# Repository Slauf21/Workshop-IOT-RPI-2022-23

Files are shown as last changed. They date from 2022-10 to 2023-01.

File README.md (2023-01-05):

# Workshop-IOT-RPI-2022-23

Steeds meer dingen – auto’s, deurbellen, rookmelders, koelkasten, noem maar op – zijn via een ‘embedded systeem’ verbonden met het internet. Internet of Things (IoT) noemen we dat. Hoe werken die systemen en wat zijn de elementaire bouwstenen om een volwaardig IoT-device te maken? In deze workshop bouwen we een eerste IoT-device. We bouwen een koppeling tussen sociale media (Telegram) en een “thing” met behulp van een Raspberry Pi-computertje verbonden met een temperatuur en luchtvochtigheid sensor, een bewegingssensor, een camera, een lichtsensor en een versnellingssensor. Dit alles doen we op een laagdrempelige manier. Alles is beschikbaar zodat je thuis - met je eigen Raspberry Pi – het werk kan voortzetten, als je dat wil.

Onderstaande linken om de benodigde applicaties te downloaden: <ins>*Indien je van thuis volgt.*</ins>

- Editor: [Notepad++](https://notepad-plus-plus.org/downloads/) (installeer de laatste versie)
- FTP-client: [FileZilla](https://filezilla-project.org/download.php?type=client)
- SSH-client: [Putty](https://www.chiark.greenend.org.uk/~sgtatham/putty/latest.html) (MSI Windows Installer: 64-bit x86:)

**Indien je de workshop volgt mag je beginnen bij [Stap 2](#2-aanmaken-van-telegram-bot).**

# Inhoudstabel

- [Workshop-IOT-RPI-2022-23](#workshop-iot-rpi-2022-23)
- [Inhoudstabel](#inhoudstabel)
- [1. Installeren en Configureren Raspberry Pi](#1-installeren-en-configureren-raspberry-pi)
  - [1.1. Installeren Raspberry Pi OS](#11-installeren-raspberry-pi-os)
  - [1.2. Raspberry Pi verbinden met wifi](#12-raspberry-pi-verbinden-met-wifi)
  - [1.3. Configureren Raspberry Pi](#13-configureren-raspberry-pi)
- [2. Aanmaken van Telegram Bot](#2-aanmaken-van-telegram-bot)
  - [2.1 Installeer Telegram](#21-installeer-telegram)
  - [2.2 Configureren van bot](#22-configureren-van-bot)
- [3. Schrijven van de code](#3-schrijven-van-de-code)
  - [3.1 Putty](#31-putty)
  - [3.1 FileZilla](#31-filezilla)
  - [3.1 Notepad++](#31-notepad)

# 1. Installeren en Configureren Raspberry Pi

Om de Raspberry PI te kunnen gebruiken voor het IOT-project moet eerst het Raspberry Pi operating system geïnstalleerd worden. Daarna moet de wifi op de Raspberry Pi geconfigureerd worden en het IP-adres genoteerd worden zodat vanaf een andere pc ingelogd kan worden op de PI via SSH. Als je de workshop volgt tijdens de demo kan je deel 1 volledig overslaan en naar deel 2 gaan. Wil je het project bij je thuis nabouwen, dan moet je eerst stap 1.1 doornemen om het project te kunnen opbouwen.

## 1.1. Installeren Raspberry Pi OS

Om het project te kunnen opstellen moet het Raspberry PI operating system geïnstalleerd worden (op een SD-kaart van minstens 16GB die volledig geformatteerd mag worden) samen met enkele installatie pakketten. Bij de Raspberry Pi die tijdens de workshop gebruikt wordt is dit al uitgevoerd. Om dit thuis ook te kunnen doen moet dit eerst nog op de SD-kaart geïnstalleerd worden. 

Eerst moet de [Raspberry Pi Imager](https://www.raspberrypi.com/software/) geïnstalleerd worden op je computer. De imager is een snelle en makkelijke manier om de Raspberry Pi OS te installeren op een SD kaart.

Steek de SD kaart in je computer en open de imager. Bij het openen van de imager word je begroet met het volgende scherm:



Om de OS te installeren klik je op 'CHOOSE OS' en selecteer je Raspberry Pi OS (32-bit). Daarna kies je de SD kaart waarop je de OS wilt zetten. Dit gebeurt door op de 'CHOOSE STORAGE' knop te klikken. Je SD kaart zal daar staan en die moet je dan selecteren.

Wanneer je de melding krijgt dat het schrijven van de image succesvol afgerond is mag je de kaart verwijderen uit je pc en in de Raspberry Pi plaatsen. Sluit vervolgens het toetsenbord, muis, camera, HDMI-scherm, en sensor bord aan. De sensoren bord is al gemaakt tijdens de workshop. Als je deze zelf wil maken kan je [hier](https://github.com/Slauf21/Workshop-IOT-RPI-2022-23/blob/main/Circuit/PCB.md) meer informatie vinden.

Nu is de Raspberry Pi klaargezet maar deze moet nog geconfigureerd worden.

## 1.2. Raspberry Pi verbinden met wifi

- Steek de Raspberry Pi in en wacht tot deze is ingeschakeld.

Startscherm:

(https://postimg.cc/5X9Gnrcb)

- Klik rechtsboven op het wifi-icoontje. Schakel de wifi in en kies voor je wifi netwerk.

(https://postimg.cc/HrsMnwM6)

- Na het selecteren van het netwerk komt er in het midden een venster tevoorschijn. Vul hier het wachtwoord van je netwerk in.

(https://postimg.cc/7GSH4Lxg)

Nu de Raspberry Pi verbonden is met het netwerk bewaren we het toegewezen IP-adres. Door over het wifi-icoontje te bewegen met de cursor zal er een venster verschijnen. Noteer deze IP-adres. Wees zeker dat je raspberry pi en je PC verbonden zijn met hetzelfde wifi netwerk.

(https://postimg.cc/k24kcH8K)

*Ons IP-adres: 169.154.146.220, niet overnemen.*

## 1.3. Configureren Raspberry Pi

Op de raspberry pi moeten we nu SSH aanzetten. Dit wordt gedaan door linksboven op de raspberry pi symbool te klikken en dan **Preferences** en dan **Raspberry Pi Configuration**. Onder de interfaces tab click je dan ssh aan.



Als volgende stap gaan we met een voorgeschreven .sh file de nodige bibliotheken afhalen en functionaliteiten aanzetten van de RPI.

Open Putty op je PC. Je wordt begroet met het volgende scherm:



Hier moet je bij hostname het ip adres van de raspberry pi ingeven. Het is noodzakelijk dat de PC en de raspberry pi op hetzelfde wifi netwerk zitten. Dan voer je als poortnummer 22 in en kies je SSH als connectie type. Dan druk je op **Open**.

- *Mogelijke waarschuwing: klik op 'Accept'*

(https://postimg.cc/R3xjwL1z)

Vervolgens zal je moeten inloggen op de Raspberry Pi. Gebruik de standaard inloggegevens als volgt:

- login as: **pi** (enter)
- password: **raspberry** (enter)

Als je je eigen login gegevens hebt gekozen, vul je die in.

*Telkens wanneer je opnieuw wilt inloggen met Putty moet je deze stappen herhalen.*

Indien je succesvol bent ingelogd ziet je terminal als volgt uit:

(https://postimg.cc/HVDD8PBP)

*Inloggegevens ter illustratie, niet overnemen.*

Met onderstaande commando's gaan we als eerst de .sh downloaden en vervolgens uitvoeren. Kopieer ze uit deze handleiding en plak ze in de putty terminal. Het plakken in een terminal wordt gedaan met de rechtermuisknop, i.p.v. de sneltoets ctrl+V. Druk op enter om ze uit te voeren.

- Downloaden script:
```javascript
wget https://raw.githubusercontent.com/Slauf21/Workshop-IOT-RPI-2022-23/main/Files/install.sh
```
- Script uitvoerbaar maken:
  - chmod +x install.sh
- Starten van script:
  - sudo ./install.sh

*Kopieer deze commando's individueel en plak met rechtermuisknop in de terminal.*

Vervolgens zal de RPI herstarten en kan er verder gegaan worden met de volgende stap.

*Log opnieuw in via Putty.*

Om nu de camera te activeren voor gebruik voer je volgende commando's in Putty.

- sudo raspi-config

(https://postimg.cc/LnmbSVKR)

- Schuif naar onder met pijltjes op het toetsenbord tot 'Interface Options' en klik op enter

(https://postimg.cc/QFFGLq1C)

- Klik op enter waar 'Legacy Camera' vermeld staat

(https://postimg.cc/CBLstcn6)

- Klik nu weer op enter om de camera te activeren

(https://postimg.cc/hhmXn98C)

- Klik een laatste keer op enter om de waarschuwing te sluiten

(https://postimg.cc/944WphJx)

Om het configuratiescherm af te sluiten toets je 'Esc' (linksboven op het toetsenbord) in.

# 2. Aanmaken van Telegram Bot

## 2.1 Installeer Telegram
We beginnen met het installeren van Telegram. Deze kan zowel op pc als op mobiel geïnstalleerd worden. Volg deze link om [Telegram Desktop](https://desktop.telegram.org/) te installeren op pc.

## 2.2 Configureren van bot
- Open telegram en zoek naar BotFather.

(https://postimg.cc/XGbcST7m)

Onderstaande venster bij invoer BotFather:

*Elk <ins>commando</ins> begint met een slash (/).*

(https://postimg.cc/ZCDGbRS3)

- Klik vervolgens op start.

Hierna verschijnt een hoop uitleg van verschillende commando's voor het aansturen van de bot.

- Om nu een bot te creëren voeren we '/newbot' in.

(https://postimg.cc/t7tpFfZT)

- Kies een naam voor je bot.

(https://postimg.cc/0r2KMpjL)

- Kies nu een gebruikersnaam voor je bot dat eindigt met bot (bv. test_bot). 

(https://postimg.cc/jDN4gzzM)

*Gebruik iets anders als 'Telegram_bot'.*

Indien naam in gebruik kan er nogmaals gevraagd worden om een gebruikersnaam in te voeren.

- Als dit succesvol is gelukt, wordt er een unieke token aangemaakt die later gebruikt wordt in de software.

(https://postimg.cc/QVJc247K)

Nu de **token** is gegenereerd gaan we niet meet met de BotFather praten, maar met onze eigen bot.

- In de zoekbalk moet je zoeken naar de gebruikersnaam van je bot (bij ons geval is dat "slauf_bot"). Die voeg je dan toe en druk je op start.



We gaan ook de chat id nodig hebben. Met deze [link](https://ungineer.github.io/chatid.html) kan je de chat id terugvinden door je **token** in het venster te plakken.

- Plak de **token** in het vakje en klik op 'Get Chat ID'.

(https://postimg.cc/5YFwP56V)

# 3. Schrijven van de code

Nu de Raspberry Pi is geïnstalleerd kunnen we beginnen met het schrijven van een Python code. Om de code te schrijven hebben we als eerst een editor nodig. Om de code te transporteren op de Raspberry Pi hebben we vervolgens een FTP-client nodig. En als laatste een SSH-client om commando's uit te voeren op de Raspberry Pi. Deze had je in het begin moeten installeren.

## 3.1 Putty

- Open Putty en voer de IP-adres in die je had teruggevonden in de vorige stappen.
- *Kijk na of 'Connection type' op SSH staat en 22 als poortnummer is gekozen.*
- Klik onderaan op 'Open'.

Er wordt nu een verbinding gemaakt met het bovenvermelde adres.

Putty

Vervolgens zal je moeten inloggen op de Raspberry Pi. Gebruik de standaard inloggegevens als volgt:

- login as: **pi** (enter)
- password: **raspberry** (enter)

<br>

Indien je succesvol bent ingelogd ziet je terminal als volgt uit:

(https://postimg.cc/HVDD8PBP)

*Inloggegevens ter illustratie, niet overnemen.*

Hierna kunnen we aan de slag met het downloaden van de start code. Deze wordt bewaard op de Raspberry Pi met de volgende commando:

```javascript
wget https://raw.githubusercontent.com/Slauf21/Workshop-IOT-RPI-2022-23/main/Python_bot/Workshop.py -O ~/Desktop/Workshop.py
```

*Bestand bewaard op bureaublad.*

## 3.1 FileZilla

- Open FileZilla en voer de gegevens in die je had teruggevonden in de vorige stappen.
  - Host: IP-adres
  - Gebruikersnaam: **pi**
  - Wachtwoord: **raspberry**
  - Poort: 22
- Klik op 'Snelverbinden' om een verbinding te maken.

(https://postimg.cc/qzB1PnLQ)

Indien je succesvol bent ingelogd ziet je scherm als volgt uit:

(https://postimg.cc/8sytRcRY)

*Links zie je de werkomgeving van je pc en rechts die van de Raspberry Pi. Nu kan er bestanden uitgewisseld worden tussen deze 2 apparaten.*

- Ga nu in de map 'Desktop' die je rechts terugvindt.
- Binnen Desktop vind je nu 'Workshop.py' die eerder was afgehaald met een link.

(https://postimg.cc/zyjTwPWk)

- Sleep deze bestand nu naar je bureaublad van je <ins>pc</ins>.

(https://postimg.cc/JHmFF26z)

## 3.1 Notepad++

- Open Notepad++ en klik linksboven op 'Bestand'.

(https://postimg.cc/CBmqkZqL)

- Klik op 'Openen' en kies voor 'Workshop.py' die op je persoonlijke bureaublad staat.

(https://postimg.cc/p5Cq9X2D)

Indien je de bestand succesvol hebt kunnen openen ziet je scherm als volgt uit:

(https://postimg.cc/HjStptyT)

- Plak vervolgens de token en chat id binnen de aanhalingstekens.

- Om deze wijziging op te slaan druk op Ctrl + S of via 'Bestand' linksboven 'Opslaan' klikken.

- Open FileZilla en sleep deze bestand vanuit je persoonlijke bureaublad aan de rechterkant binnen het map 'Desktop'.

(https://postimg.cc/yWd7gVk0)

*Vink 'Deze actie altijd gebruiken' en klik op 'OK' als je een waarschuwing krijgt over 'Doelbestand bestaat al'.*

Nu de bijgewerkte versie van de code op de Raspberry Pi staat kunnen we deze runnen.

- Open Putty en tik 'cd Desktop/' in om in het bureaublad te zitten waar de code zich bevindt.

- Tik nu 'python3 Workshop.py' in om de code te runnen.

Indien je de bestand succesvol hebt kunnen runnen ziet je scherm als volgt uit:

(https://postimg.cc/t1pNDv6G)

Nu heb je de basis bereikt, om nu de interessante delen toe te voegen in je code klik je op deze [link](https://github.com/Slauf21/Workshop-IOT-RPI-2022-23/wiki).

Verder zal je hardware aansturen gelijk PiCamera om foto's te nemen, DHT11 om temperatuurmetingen uit te voeren enzovoort.

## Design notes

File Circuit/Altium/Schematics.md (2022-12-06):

# Schematic

[RPI pins header detailed](https://user-images.githubusercontent.com/79916416/205603582-8edb5c64-c594-4c13-aa63-774d3fb8d8f8.png)

The PCB will be designed in Altium designer. In Altium create a new project and add a schematic to the project. The components will be put on this schematic. 
A lot of the sensors we read are external, meaning they are their own circuit boards and need to be connected with headers. The PCB will sit on the RPI headers. 
Here are the measurements of the pin headers:


*Measurements in millimeters*

[Library Loader](https://www.samacsys.com/altium-designer-library-instructions/) is a software that allows you to import libraries for components. These include pre made footprints and schematic icons. This will be used for the SGP40 sensor

## Pin Header
These pin headers are not basic components in Altium and need to be created with a footprint wizard. Before starting create a libs folder in the Altium project.

 <br>
*Libs Folder*

### PCB Footprint
To add a custom component right click the project (.PrjPcb file) 
then **Add New To Project** -> **PCB Library**. The new file will be openned and will be blank. On the left panel a footprint is visible. This one wont be used. Press **CTRL+S** and save the file in the **Libs** folder.

<br>
*Default Footprint*

<br>

First the header for the RPI GPIO will be created. To create a new footprint press the **Tools** tab on the toolbar and select **Footprint Wizard**. A new Footprint Wizard window will open. Press next and select the type of footprint needed. A header is a **Dual In Line Package (DIP)**. Change the unit of measurement to **millimeters**

Next you will be asked for the hole dimensions. The dimensions from the measurements above need to be used. The pin diameters of the header is 1.02mm. A slightly wider diameter of 1.2mm will be used so the header can fit into the holes easily. Dimensions of the pad can be 2mm by 2mm. 

<br>
*Hole Dimensions*

<br>

Press next and now the distance between the pins need to be determined. The measurements say thet header pins are 2.54mm from each other. Since the hole and pad size was set to 2mm by 2mm there will be 1mm from the hole center to the edge of the pad. This will result in 0.54mm of free space between the pads.

<br>
*Hole Distance*

<br>

The width of the outline can be left as it is. This outline will be deleted later.
Next the total number of pins need to be selected. The rpi 3b has 40 GPIO pins in a 2x20 structure.

<br>
*Pin Amounts*

<br>

Call it RPI-Header and then click finish.

The design will appear on screen and the first this that needs to be done is to delete the yellow outline by selecting it and pressing delete. Then delete the original footprint. Result:

<br>
*New Footprint*

### Schematic Icon

A new component also needs a schematic icon to put on the schematic design. This is done by adding a schematic library to the project like a PCB library was added. 
Name it the same as the PCB library and save it under the same directory (Libs). Select the icon item and press edit. Under the new tab call the icon **RPI-Header*. The custom footprint needs to be linked to this icon. This is done by pressing the add footprint button at the bottom.

A window will appear to select a library. Press browse, then select the correct library called RPI-Header.

<br>
*Add Footprint*

<br>
*Select Library*

Press OK, then OK again. The footprint is succesfully linked to the icon. Now an actually schematic icon needs to be created.

To do this press **Tools** -> **Symbol Wizard** in the toolbar. A new window will apear asking the layout. RPI gpio has 40 pins in a zig zag style. Seelct zig zag in the layout style. Now all the pins are set as inputs. Select them all by first selecting the first, then holding shift and pressing the last one. Change the electrical type from Inputs to I/O by clicking the drop down menu of the last item.

<br>
*Icon Design*

Then **Place** -> **Place New Symbol**

In the SCH LIB window select the icon and press place. Place it somewhere on the schematic. Double click it and give it the name J1

## Sensors

The same process needs to be repeated for the sensor headers. This is a 5x1, 3x1 and 2 times 1x4 headers. When creating a one dimensional header like a 4x1. Select 8 pins for the DIP and remove one of the sides.



## Screw Terminals

The screw terminals dont have the same measurments as pin headers. 

<br>
*Screw Terminal Header*

<br>
*Hole Measurements*

<br>
*On Schematic*

## Relais

The relais has a much different pin design the a header or terminal. 

<br>
*Relais Measurements*

<br>
*Footprint*

The distance is the distance that was written in mm in the datasheet converted to mils.

<br>
*Schematic Icon*

The schematic icon pin numbering is the same as the pins on the datasheet of the relais.

## Resistors and Capacitors

Throught hole resistors are used. These are already included in the standard library of Altium. In the components search, select miscellanious devices from the drop down menu and search for Res1. The same method is used for importing capactitors.

<br>
*Miscellanious Devices*

## Wiring the Schematic

After adding all the components, the schematic should look like this:

<br>
*Schematic Not-Wired*

Now all the components need to be wired to the RPI header. For this, a [rpi gpio pinout](https://www.raspberrypi.com/documentation/computers/images/GPIO-Pinout-Diagram-2.png) picture is usefull. The right side of the gpio pins should be used as much as possible because the pcb is going to sit on the right side of the RPI.

Pin 16 is a free GPIO pin that will be used to drive the transistor base. Connect it to the pin number 2 of transistor Q1 with the 1.2k ohm resistor in between. The collector of the transsitor needs to be connected to the 5V power supply of the RPi which is pins 2 or 4. This will then power the coil, which needs to be connected to the emitter of the transtor (pin 3). Wires can be placed using CTRL+W command. Looking at [the data sheet of the relais](https://www.mouser.be/datasheet/2/307/Omron_(ENG)G5PZ_E-1843616.pdf), the coil is between pins 1 and 4 and the contact is between 2 and 3. Connect the Emitter of the BJT to pin 1 of the relais, then connect pin 4 to ground of the RPI.

Then the screw terminals need to be connected through the contact of the relais. Pins 2 and 3 can be connected since they are neutral and earth, but pins one will be live and need to go to the contact of the coil. The fly back diode 1n4007G needs to be connected reverse and in parallel with the coil. This means the anode will be connected to pin 4 and the kathode to pin 1 of the relais. 

The [DHT11](https://www.google.com/search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) has 3 connected pins. Vcc, Data and fround. It also needs a resistor between the data and the 5V. Pin 1 will be connected to the same 5V pin. Pin 2 will be connected to pin7 which is the gpio pin that support 1 wire protocol. 3 is not connected and 4 is ground which is pin 6. Also connect the 10k resistor between dht pins 1 and 2.

The mic uses and SPI ADC to convert the analog data to digital. Here are its pinouts:

<br>
*LTC1864 Pinouts*

Align the headers in the schematic to match the pinouts. This will create less confusion.

<br>
*Schematic Pinout LTC1864*

This component is devided into tho headers, one 4x1 header for each side. Vcc (Pin8) and Vref (pin1) need to be connected with 5V. [Here](https://www.cuidevices.com/product/resource/cma-4544pf-w.pdf) is the mic basic operation circuit. The output will go to the SPI adc converter.

Pins 5 (CONV),6 (SDO) and 7 (SCK) are the SPI pins. The SDO and SCK need to be connected to the MISO and SCLK pins on the RPI respectivly. WHich are pins 21 and 23. The CONV pin is the slave select and needs to be connected to SPI0 CE1 pin.

The [PIR motion sensor](https://www.mouser.be/datasheet/2/737/pir_passive_infrared_proximity_motion_sensor-932858.pdf) has 3 simple connectors. Pin 1 is the vcc, Pin2 is the data and pin 3 is the GND. Pin 22 will be used for the data of the PIR motion sensor.

The [gas sensor](https://www.mouser.be/datasheet/2/682/Sensirion_Gas_Sensors_Datasheet_SGP40-2001008.pdf) also has a reading circuit. This will be recreated in altium.

## Result

The schematic will look like this:

<br>
*Resulting Schematic*

Then the next step is to design the PCB. This can be read [here](https://github.com/Slauf21/Workshop-IOT-RPI-2022-23/blob/main/Circuit/Altium/PCB.md).

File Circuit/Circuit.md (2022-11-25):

# Circuit
TO BE UPDATED

## RPI componenten
| Component | Beschrijving | Aantal |
|---|---|---|
| RPI 3b | Raspberry Pi 3b | 1 |
| 16GB SD | SD kaart 16GB | 1 |
| RPI camera | Raspberry Pi Camera | 1 |
| Micro USB adapter | Micro USB Adapter | 1 |

## Circuit componenten
| Component | Beschrijving | Hoeveelheid |
|---|---|---|
| DHT-11 | Temperatuur-Luchtvochtigheid sensor | 1 - |
| G5PZ-1A-E 5VDC | Relais - Spoel 5V | 1 - |
| DYP-ME003 | Beweging sensor | 1 |
| 1x3 | Schroef terminal | 2 - |
| 2x20 | RPI Header | 1 - |
| 1n4007g | Flyback Diode | 1 - |
| 10kohm | Weerstand | 1 - |
| 1.2kohm | Weerstand | 1 - |
| SGP30 | Gas Sensor | 1 - |
| MAX 4466 | Microfoon | 1 - |
| TCS34725 | RGB sensor | 1 |
| SSOP8 | SPI-ADC | 1 - |
| 2n2222 | BJT transistor | 1 - |

## Schematic 

Read about how the pins of the circuit are connected and how it is designed [here](https://github.com/Slauf21/Workshop-IOT-RPI-2022-23/blob/main/Circuit/Altium/Schematics.md).

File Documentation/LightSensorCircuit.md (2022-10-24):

# Light Sensor Circuit
The LDR needs to be read with an ADC then sent to the RPI.

## LDR
LDR: https://www.gotron.be/ldr-photoresistor-100mw-50-160kohm.html

The LDR will assume a resistance value depending on the incidence of light. The voltage across this will therefore vary and be an analog value. For this we need an ADC.



## ADC
ADC TLC549: https://www.gotron.be/8-bit-adc-converter-with-serial-control.html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

Datasheet: https://pdf1.alldatasheet.com/datasheet-pdf/view/28912/TI/TLC549.html



### Working Principle

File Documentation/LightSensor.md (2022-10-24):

# Light Sensor
LDR inlezen via een adc en doorsturen naar de raspberry pi met SPI.

## LDR
LDR: https://www.gotron.be/ldr-photoresistor-100mw-50-160kohm.html

De LDR gaat een weerstandswaarde aannemen afhankelijk van de lichtinval. De spanning hierover gaat dus varieren en een analoge waarde zijn. Hiervoor hebben we een ADC nodig.



## ADC
ADC TLC549: https://www.gotron.be/8-bit-adc-converter-with-serial-control.html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



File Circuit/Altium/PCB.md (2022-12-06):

# PCB 

Add a PCB document to the project like you added a schematic. The first step will be to define the boards shape. It will go over the RPI and allign with the screwholes on the RPI. These measurements of the rpi can be found its [datasheet](https://static.raspberrypi.org/files/product-briefs/Raspberry-Pi-Model-Bplus-Product-Brief.pdf).

The PCB will come on the RPI like this:



Define the PCB Shape by first adding the holes. These are regular holes with diameter that alligns to the screwholes. The distances need to be placed correct too like in the measurements. The command jump to location can be used for precise movements. This is done by clicking J on the keyboard and then new location. 

For the shape itself switch to the mechanical layer and then use the same jump to location position to trace wires across the board:

<br>
*Wires Board Shape*

Round edges will make the PCB cleaner. The RPI has 3.0mm radius on its edges. This will be copied on the PCB. The radius is 3mm, meaning that from the edges the lines need to be reduced by 3mm.

<br>
*Round Edges*

Now to actually define the boardshape hold shift and click on all the edge pieces to select them all. Then go to Design tab on the toolbar -> "Board Shape" -> "Redefine Boardshape From Selected Objects".

The edge pieces can now be deleted.

<br>
*Final Board Shape*

Now its a matter of placing all the components in the most efficient way. The RPI header will go all the way on the right. A little space needs to be left because two tracks will come from the right side.

<br>
*Components Placed*

The top and bottom layers are used to wire the components:

<br>
*Wired PCB*

A ground plane will be added using polygon pour. Right click on the PCB -> Place -> Polygon Pour. Then draw to the edges and skip the round corners for now.  Make sure to swap to the bottom layer first.

<br>
*Polygon without corners*

Now the corners can be dragged to become round by pressing space while holding the corners.

<br>
*Correct Polygon Pour*

And with that the PCB is finished.

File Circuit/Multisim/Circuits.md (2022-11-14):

## RPI GPIO to Relais Circuit

De spoel heeft een spanning van 5V nodig en een stroom van 106mA die er doorheen loopt om bekrachtigt te worden. De RPI GPIO-pinnen hebben een output van 3,3V en kunnen maximaal 16mA leveren. Dit betekent dat de RPI de spoel van het relais niet kan voeden met zijn GPIO-pinnen. 

Een transistor moet als schakelaar worden gebruikt. Zo kan de GPIO pin de transistor aansturen waardoor de RPI controle heeft over een hogere stroomkring. De 5V-pin van de RPI is direct aangesloten op de voeding en kan 1-2A stroom leveren. Dit is meer dan nodig en zal dus gebruikt worden voor de spoel aan te sturen.

De schakeling is als volgt:



R3 is de spoel. Volgens de datasheet heeft hij een weerstand van 47 ohm. De collector stroom Ic is eenvoudig te bepalen. Gebruik de wet van Ohm om de spanning over de spoel te delen door de weerstand van de spoel.
De spanning over de spoel moet 5V zijn. Dit resulteert in een stroom van 106mA. Er wordt veronderstelt dat de spanningsval over de transistor 0V is. In werkelijkheid is dit niet het geval.
Maar de spanning over de collector en de emitter is klein genoeg om te negeren.

Er moet 0,7V over de basis en emitter van de transistor te staan voor geleiding. Hiervoor is een weerstand nodig om de 2.6V van de 3.3V op te nemen. De BJT is een stroomgestuurde transistor. Dit betekent dat de totale Ic evenredig zal zijn met de Ib. De DC-stroomversterking is de factor die de relatie bepaalt. Dit is te vinden in de datasheet en laat zien met welke factor Ic groter is dan Ib.

De juiste Hfe of stroomversterkingsfactor wordt gevonden door het gedissipeerde vermogen van de BJT te berekenen, namelijk P = Uce * Ic. Doe vervolgens hetzelfde voor de voorwaarden van de Hfe-waarden in de datasheet. Kies de Hfe waarvan de P-waarde het dichtst bij de berekende P in het circuit ligt. Dit wordt gebruikt als de stroomversterking. Op die manier zijn de spanning over de weerstand en de stroom erdoor bekend. Met behulp van de wet van Ohm wordt berekend dat een weerstand van 1250 ohm nodig is. De werkelijke waarde van het sluiten is een weerstand van 1,2 kohm.

De basis stroom is minder dan de maximum stroom van de RPI GPIO pinnen, namelijk 16mA

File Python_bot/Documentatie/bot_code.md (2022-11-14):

# Telegram bot

<ins> Create a new bot </ins>

1. Open telegram and search for 'BotFather'
2. Click on the 'start' button or type '/start'
3. Type '/newbot'
4. Choose a name for your bot
5. Choose a username for your bot
6. You will get a message that contains a token to access the HTTP API

<ins> Python code </ins>

#### Import libraries
Some necessary libraries. Telebot is a Telegram bot library.

(https://postimg.cc/QF4S4MHP)

#### Key
Declaration of the personal token and initializes a connection to the bot.

(https://postimg.cc/75LLFj8C)

(https://postimg.cc/k2kBWwzB)

#### Pi camera
Then we create an object from the PiCamera class. When we create this object, the camera will start initializing itself. The resolution is also initialized.

*To use the PiCamera module, you will need to enable legacy support for the camera. (sudo raspi-config)*

(https://postimg.cc/SjvqXRwK)

#### DHT 11
Create a DHT object from the Adafruit_DHT class. Gpio refers to the data pin of the sensor.

(https://postimg.cc/3kjPZxbm)

#### Commands
The first command sends a fix reply when the user sends 'hallo'. When the second command is called, the Pi camera takes a picture and saves it to the specified path. After this, the picture will be sent as reply. The third command takes care of the measurement of temperature and humidity. The measuring will also be sent as reply.

(https://postimg.cc/hfTwSGn6)

<ins> Results </ins>

Taking a picture with Pi camera:

(https://postimg.cc/xXFLhK72)

Measuring the temperature/humidity with DHT11:



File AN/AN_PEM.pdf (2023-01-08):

# Workshop IOT met RPI

Author Rauf Pere
Ferdi Ileri

## Abstract

Dit abstract bevat een workshop voor studenten waarbij ze in aanraking komen met hardware en software. Het doel is om via een Telegram bot commando’s te sturen om de bijhorende hardware sensoren aan te sturen.

De focus ligt op het volledig uitwerken van een workshop. Deze bevat de volledige installatie van een Raspberry Pi tot het schrijven van een Python code. Er worden oefeningen voorzien voor de studenten die behandeld moeten worden tijdens de workshop.

Studenten moeten zelf instructies kunnen ingeven aan de Raspberry Pi die zorgen voor het aansturen van een software. De softwareoefeningen bevatten witte ruimtes voor studenten die zij dan kunnen invullen na het hanteren van de basis oefeningen.

De doelstelling die we kregen van de docenten was het volledig omzetten van een Discord bot naar een Telegram bot. Dit was vooral een aanpassing in de software maar de hardware speelt hier natuurlijk ook een rol.

Het resultaat is een volledig werkende Telegram bot dat draait op een Raspberry Pi. Met verschillende commando’s vanuit Telegram Desktop of mobiel kunnen verschillende hardwarecomponenten aangestuurd worden.

Deze workshop zou erg benut kunnen worden met een uitbreiding van de hardware en software die mee is met de hedendaagse technologieën.

## Inhoudstabel

## 1 Introductie

In deze application note wordt een manier besproken om sensoren via wifi te bedienen. De onderzoeksvraag van het project was de mogelijkheid analyseren om te werken met een Telegram bot en dit uit te werken. Het project bouwt verder op een al bestaande opstelling. Vanuit de bestaande workshop zijn er wijzigingen in gebracht. De software die gebruikt werd om een Discord bot aan te sturen is ook als referentie gebruikt. De algemene configuratie van de componenten blijven merendeels voor beide gelijk waarbij het verschil in het opstellen van de bot zelf zit. Het doel is dan om de gebruikte Discord bot in de originele opstelling om te vormen naar een Telegram bot en nieuwe hardware toe te voegen aan de PCB. Het project kan enigszins opgedeeld worden in twee delen. Het eerste deel houdt in het werking stellen van de hardware die in het vorig project gebruikt werd via Telegram. Het tweede deel bevat het toevoegen van nieuwe hardwarecomponenten en deze bijhorend uit te werken met de Telegram bot.

De volgende zaken zullen besproken worden:

- Raspberry Pi
- Telegram Bot
- Sensoren
- Schakelingen
- PCB
- Python code

## 2 Materialen en methoden

Als programmeertaal wordt Python gebruikt. Dit is de taal die in het beginproject werd gebruikt en is ook de standaardtaal op de Raspberry Pi. Het is ook mogelijk om C++ te programmeren, maar dit geeft geen meerwaarde.

De geschreven software wordt gedraaid op de Raspberry Pi. Een Raspberry Pi is een klein, betaalbaar computerboard dat ontwikkeld is om mensen te helpen leren hoe ze computerprogramma's kunnen schrijven en om elektronische projecten kunnen maken. Het board is ongeveer zo groot als een creditcard en bevat een processor, geheugen, en aansluitingen voor verschillende soorten randapparatuur, zoals beeldschermen en toetsenborden. Het is een ideale instap voor de IoT.

Discord was de originele client en die is vervangen door Telegram. Om de PCB te ontwerpen is Altium Designer gebruikt. Dit is het programma dat altijd is gebruikt in de opleiding. Multisim is gebruikt om schakelingen te simuleren.

Voor hardware zijn de volgende overgenomen:

- DHT11 temperatuur- en luchtvochtigheidsensor
- PIR-beweging sensor
- Relais
- Pi Camera

Hier is nieuw hardware aan toegevoegd:

- Analoge microfoon
- LTC1864 SPI gestuurde ADC
- SGP40 gas sensor

Sommige componenten hebben hun eigen uitlees circuits. Deze hebben dan nog extra componenten die in de materialen lijst ook staan. Er was een keuze om de microfoon en de gas sensor als break-out PCB’s of als losse componenten te gebruiken. De voordelen van de break-out borden zijn dat ze kant en klaar in headers aan de PCB gestoken kunnen worden. Het garandeert makkelijke werking. Het voordeel van de losse componenten is dat ze goedkoper zijn, en ervaring geeft aan de ontwerper. Er is ook door die twee voordelen gekozen om losse componenten te gebruiken.

De ontworpen PCB gaat op RPI zitten. De PCB is zo gemaakt dat de RPI GPIO pins door de soldeergaten gaan en de schroefgaten van de RPI overeenkomen met die van de nieuwe PCB. Zo worden er standoffs gebruikt om het gewicht van de PCB en sensoren te steunen.

Voor de PCB zijn through-hole componenten gebruikt waar dat ging. Op deze manier konden we de schakelingen op een breadboard testen met de Raspberry Pi vooraleer de componenten op de printplaat gesoldeerd werden. De enige SMD-component is de SGP40 gas sensor. Deze komt enkel in één package en die is in SMD.

Voor de gas sensor werd er een keuze gemaakt tussen de SGP30 en SGP40. De SGP30 is de sensor die op het break-out bordje gebuikt werd. Maar de sensor zelf werkt op een voedingspanning van 1.6-1.9V. Dit betekent dat de GPIO-spanning van de RPI verlaagt moet worden. De SGP40 daarentegen heeft een voedingspanning bereik van 1.7V tot 3.6V. De GPIO-spanning van 3.3V valt hier goed binnen. Om deze redenen is de SGP40 verkozen.

De data die wordt ingelezen van de microfoon is analoog. De Raspberry Pi bevat geen inwendige ADC om deze data om te vormen. Hierdoor moest er gebruikt gemaakt worden van een externe ADC. Dit is de LTC1864 in het project. De LTC1864 is een 16 bit ADC die zijn digitale data via het I²C protocol kan doorsturen.

Er kon ook gekozen worden om een RGB-sensor, LDR of accelerometer te gebruiken. Door gebrek aan tijd konden alle sensoren niet tegelijk gebruikt worden. De RGB-sensor, LDR en accelerometer zijn dus niet gekozen. De RGB-sensor had niet echt een nut in de opstelling, vergeleken met een microfoon en gas sensor. De ingelezen data is niet zo interessant als andere sensoren in het project. De LDR is eruit gelaten omdat dit een analoge sensor is en dus gelijk de microfoon een ADC zou nodig hebben. Sinds er al een sensor met een ADC gebruikt wordt is de LDR uit het project gelaten. De accelerometer is niet gekozen omdat het data kan inlezen bij het bewegen van de ganse opstelling. Dit leek ons onhandig. Het leek beter om meer sensoren te gebruiken met verschillende soorten data.

Hier is een schematische voorstelling van het principe van het project:

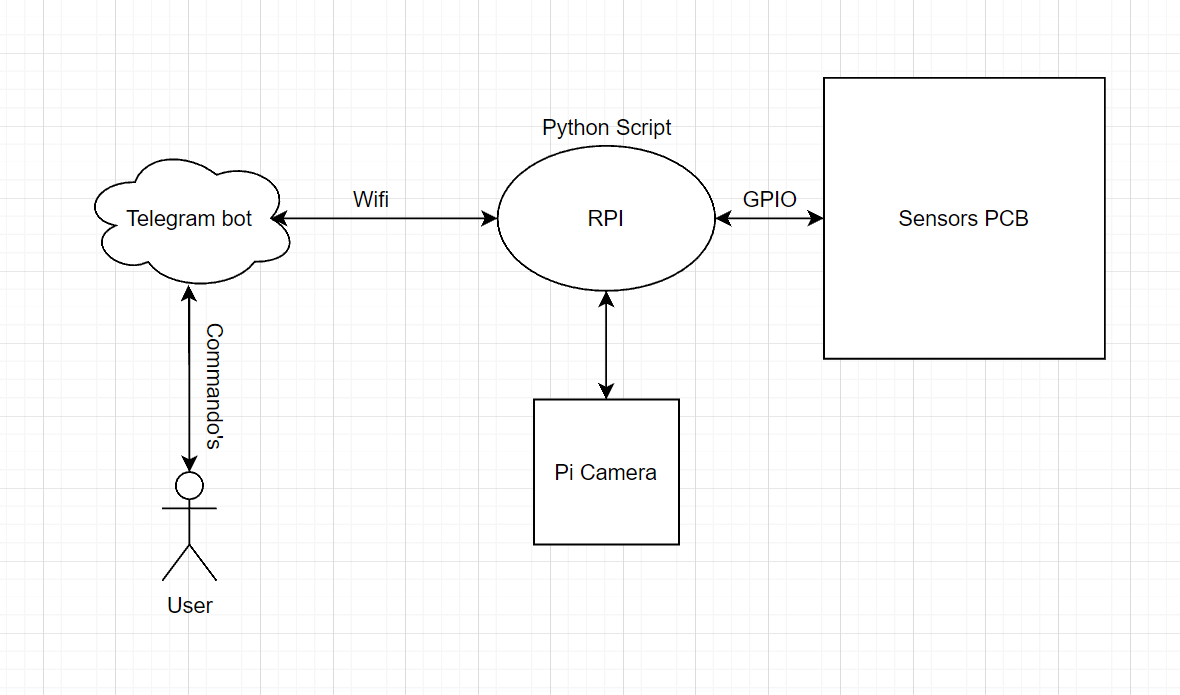
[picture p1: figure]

Een Telegram bot is een account dat is opgezet als een soort app of programma binnen de chat-app Telegram. Het is gemaakt om automatisch te reageren op specifieke commando's of op bepaalde gebeurtenissen die plaatsvinden in een chatgesprek. Dit gebeurt allemaal via het internet, zodat gebruikers de bot kunnen gebruiken vanuit elke locatie met een internetverbinding.

De user stuurt commando’s naar de telegram bot. Dit kan via het installeren van Telegram op een desktop of simpelweg op een mobiele toestel. Deze commando’s zijn vooraf gekozen en ingesteld in de code waarop deze moeten reageren. De bot stuurt deze commando’s dan door naar de Python code op de Raspberry Pi. Afhankelijk van de commando zal er in de code een interactie uitgevoerd worden met de sensoren/Pi Camera. Het script zal het resultaat dan terug naar de user sturen via de Telegram bot. Op deze manier kan er gegevens opgevraagd worden zoals het temperatuur en luchtvochtigheid, een instant foto waar de Raspberry Pi zicht bevindt of een signaal wordt gestuurd als er beweging optreedt in de ruimte. Het relais kan alsook aangestuurd worden met een gekozen uitgang. Zo kan circuit met een grotere belasting aangestuurd worden door de Raspberry Pi (bijvoorbeeld een motor).

## 3 Resultaten

### 3.1 Telegram Bot

Naar aanleiding de onderzoeksvraag is er bewezen dat de PCB met bijhorende hardware aangestuurd kan worden via een Telegram bot. Hieronder een conclusie van de behaalde resultaten.

3.1.1 Constante commando
Er kan commando’s opgesteld worden met bijhorende functie die vragen kan afhandelen. Onderstaande is een commando die automatisch reageert met een vooringestelde tekst.

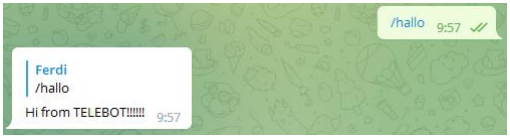
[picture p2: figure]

3.1.2 PiCamera
Met behulp van een PiCamera kan een afbeelding gemaakt worden. Een uitbreiding hiervan zou kunnen zijn (indien mogelijk) om real time beeld te tonen of om op beelden op te nemen (video).

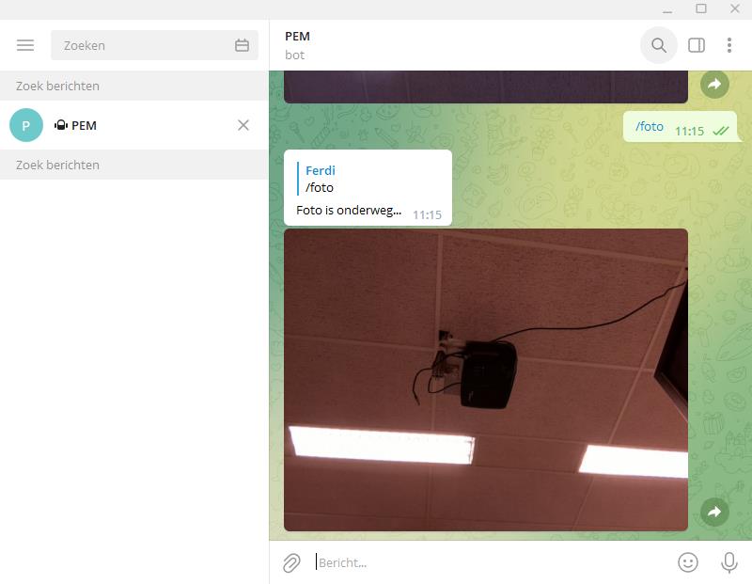
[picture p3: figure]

3.1.3 DHT11
DHT11 dat zorgt voor een temperatuur en vochtigheid meting. De resultaten hiervan kunnen afwijken van de werkelijke temperatuur en vochtigheid.

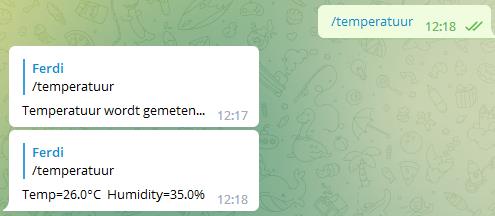
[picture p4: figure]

3.1.4 Relais
Het relais kan aangestuurd worden met twee commando’s. Hierop zijn geen verdere testen uitgevoerd met een specifieke uitgang. In de toekomst zou er verdiept kunnen worden om te bepalen welke uitgangen er aangesloten kunnen worden.

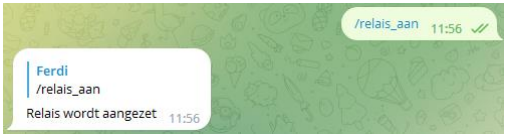
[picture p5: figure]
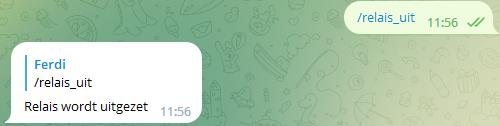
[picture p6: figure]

3.1.5 Bewegingssensor
Aan de hand van een bewegingssensor kunnen er meldingen ontvangen worden wanneer er beweging wordt gedetecteerd door de sensor. Bijkomend wordt het uur meegegeven om de persoon duidelijk te maken op welke tijdstip een detectie is opgenomen.

De bewegingssensor kan enkel aangezet worden waarbij deze continu aan het detecteren is. Een mogelijke uitbreiding zou het uitzetten van deze sensor kunnen zijn.

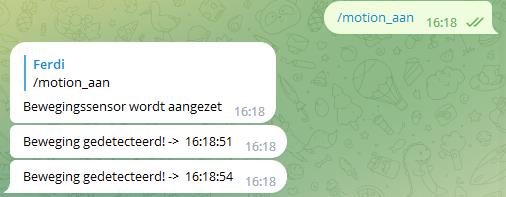
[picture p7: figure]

3.1.6 Gas sensor (nieuwe hardware)
De gassensor maakt het mogelijk om de luchtkwaliteit te meten. Waaronder CO2 en TVOC (chemische stoffen) gemeten kunnen worden. De resultaten hiervan kunnen afwijken van de werkelijke omstandigheden. Ook hierop kan er verder ontwikkeld worden om bijvoorbeeld meerdere soorten gassen te meten.

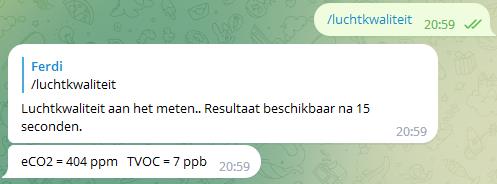
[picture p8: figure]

### 3.2 Circuit

Elektronische schakelingen zijn gemaakt om de sensoren uit te lezen en de spoel aan te sturen.
3.2.1 Relais aansturen
De Raspberry Pi kan de spoel van 5V niet aansturen met zijn 3.3V GPIO-pin’s. Hij heeft wel een 5V power pin die de spoel kan bekrachtigen. Hiervoor is een transistor circuit gemaakt die waarbij de GPIO pin de transistor schakelt en zo de spoel bekrachtigt kan worden door de 5V power pin.

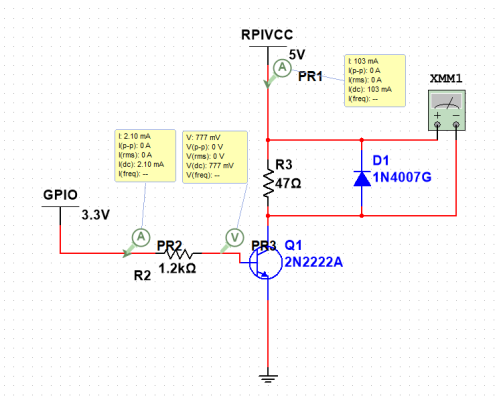
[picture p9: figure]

3.2.2 SGP 40 applicatie circuit
De SGP40 heeft een basis circuit die meegegeven is in de datasheet. Deze moet nagebouwd worden om de sensor uit te lezen en aan te spreken met I²C.

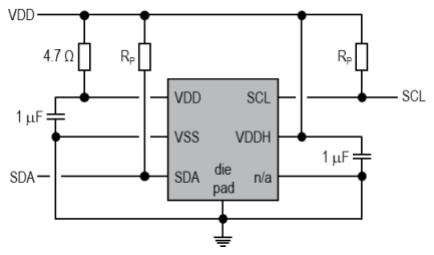
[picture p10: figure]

3.2.3 Analoog microfoon circuit
De microfoon heeft een basis uitlees circuit in de datasheet

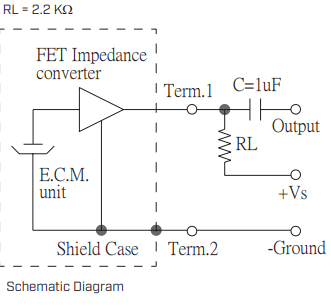
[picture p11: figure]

3.2.4 LTC1864 ADC
De LTC1864 bezit enkel een condensator in zijn basis circuit.

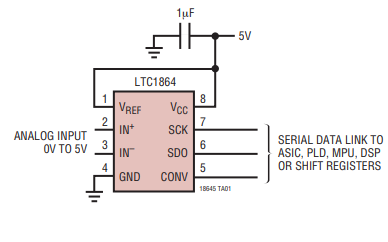
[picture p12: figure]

3.2.5 PCB
Een PCB is ontworpen voor makkelijk uitlezen van de hardware op de RPI. De breedte komt overeen met de RPI en de schroefgaten lijnen uit met de schroefgaten op de RPI.

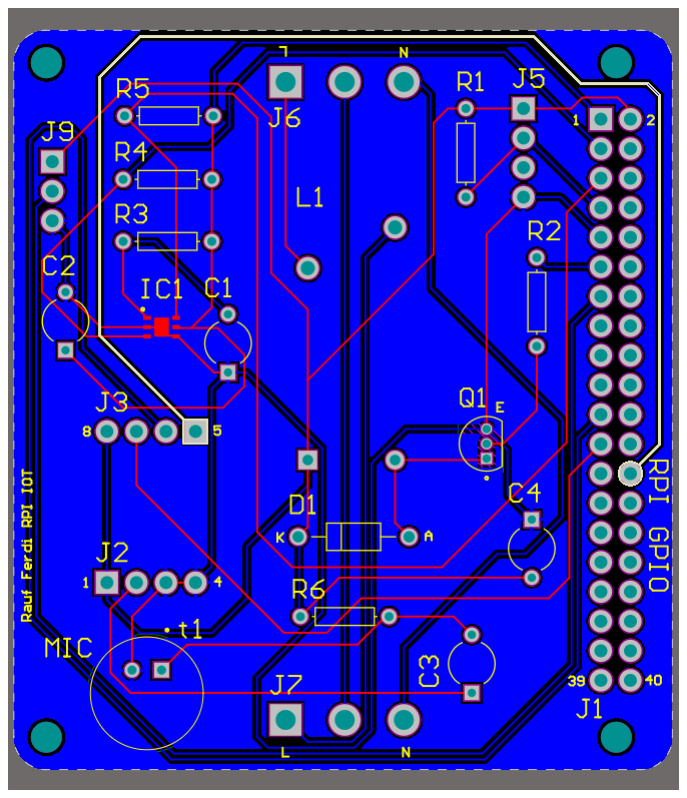
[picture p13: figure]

## 4 Discussie

### 4.1 Telegram bot

4.1.1 Python code
Een python code is geschreven om de hardware te controleren op aansturing van de telegram bot. De uitleg van de code gaat als volgt.

4.1.1.1 Bibliotheken
Onderstaande bibliotheken zijn noodzakelijk om de Python code te runnen. Bibliotheken dienen om de functionaliteit van een component te kunnen gebruiken.

Telebot is een van de belangrijkste bibliotheken die gebruikt wordt om de bot op te stellen en ook zorgt voor de communicatie. Verder staan er bibliotheken in om voor het gebruik van sensoren en GPIO.

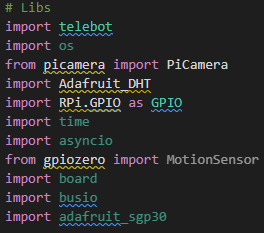
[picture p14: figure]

4.1.1.2 Telegram token
Ieder gebruiker van Telegram heeft een persoonlijke account om de functionaliteiten ervan te kunnen gebruiken. Bij het aanmaken van een bot wordt er automatisch een token (API_KEY) gegenereerd. Deze is nodig om te kunnen communiceren en verwijst dus naar het account waarvan het is aangemaakt. De chat id daarentegen verwijst naar om een specifieke chat te selecteren en hiermee communicatie uit te wisselen.

Aan de hand van Telebot uit telebot bibliotheek wordt er verbinding gemaakt met de gespecifieerde token.

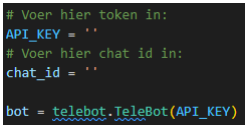
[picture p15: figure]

4.1.1.3 Constante commando
Om een bot aan te maken wordt er een message handler gebruikt. Deze wordt gebruikt om specifieke functies te koppelen aan bepaalde soorten berichten die door een bot worden ontvangen.

Wanneer er /hallo ontvangen wordt zal de bot dit afhandelen door een constant gespecifieerd bericht te sturen. Reply to stuurt een antwoord terug waarin ‘Hi from TELEBOT!!!!!!’ staat.

Onderaan het programma moet bot polling geplaatst worden om de programma continu te laten lopen. Op deze manier kan er constant handelingen uitgevoerd worden.

4.1.1.4 PiCamera
Om een foto te kunnen maken wordt er gebruik gemaakt van een PiCamera. In de onderstaande code wordt een nieuw object van het type PiCamera gemaakt en wordt de resolutie van de camera ingesteld op 640x480 pixels. Deze resolutie is een veelgebruikte standaardresolutie voor video’s en kan geschikt zijn voor veel toepassingen.

De methode om een commando aan te maken blijft voor elk onderdeel hetzelfde. Enkel de functie waarin een handeling uitgevoerd wordt verandert.

Bij deze wordt er eerst een bericht gestuurd dat de foto onderweg is. Bijgevolg wordt er met capture een instant foto genomen en bewaard onder een gespecifieerde locatie op de Raspberry Pi. Send photo stuurt het opgeslagen foto door. Hierin is ook de chat id meegegeven om te duiden over welke chat het gaat. Deze variabele is dus enkel noodzakelijk in dergelijke functies.

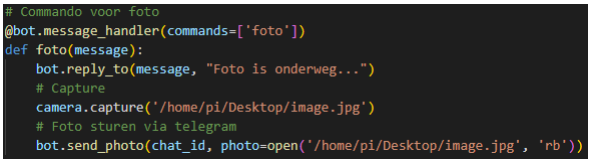
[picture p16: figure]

4.1.1.5 DHT11
Aan de hand van een DHT11 kan de temperatuur en de vochtigheid gemeten worden.

Dht sensor is een variabele waarin er DHT11 aan gekoppeld wordt uit de bibliotheek. Vervolgens wordt een tweede variabele aangemaakt waarin een pinnummer aangekoppeld wordt. Deze pinnummer is de pin op de Raspberry Pi die verbonden is met de data pin van de sensor.

Na het verzenden van een constant bericht wordt er met read retry continu metingen uitgevoerd. Met reply to wordt deze meting dan teruggestuurd.

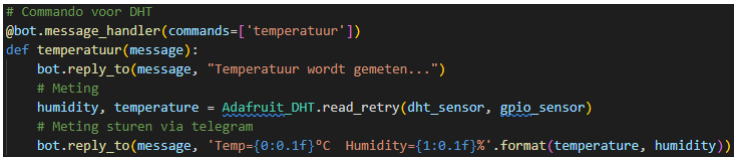
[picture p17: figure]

4.1.1.6 Relais
Om een relais aan te sturen worden er twee verschillende commando’s aangemaakt. Relais aan dient om deze aan te zetten en relais uit om deze weer af te zetten.

De eerste regel zet de modus van de GPIO-poorten op BCM-nummering. De tweede regel definieert een variabele gpio relais en stelt deze gelijk aan 21. Dit is het BCM-nummer van de GPIO-poort die verbonden is met het relais. De derde regel gebruikt de functie setup uit de GPIO-module om de poort met het BCM-nummer 21 als uitgang te configureren. Dit betekent dat de GPIO-poort 21 kan worden gebruikt om een signaal naar een apparaat te sturen dat is verbonden met de Raspberry Pi.

Telkens wordt bij beide commando’s de GPIO-uitgang hoog (HIGH) of laag (LOW) gezet om het relais te schakelen.

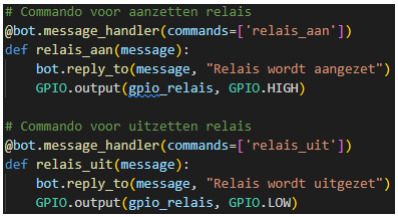
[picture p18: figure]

4.1.1.7 Bewegingssensor
Met behulp van een bewegingssensor of PIR-sensor kan er gedetecteerd worden of er beweging plaatsvindt in een ruimte.

In de volgende regel wordt een MotionSensor object aangemaakt dat verbonden is met GPIO-pin 4.

Vervolgens wordt weer een commando aangemaakt om deze keer de bewegingssensor op te roepen. Binnen deze commando wordt ook een functie motion det opgeroepen. De functie zorgt voor het uitlezen van de sensor.

Binnen de functie motion det zorgt de while lus dat onderstaande continu uitgevoerd wordt. Met if pir.motion_detected wordt er afgevraagd of er beweging is en indien er beweging is zal er een bericht met het uur gestuurd worden. Er wordt een vertraging gezet in de functie van 3 seconden met 'time.sleep'. Dit is nodig zodat er geen oneindig veel berichten gestuurd wordt.

4.1.1.8 Gas sensor (nieuwe hardware)
Om een gassensor uit te lezen wordt er gebruik gemaakt van het I2C protocol.

In de volgende regels wordt een I2C-object aangemaakt met behulp van de board.SCL- en board.SDA-pins, wat de seriële klok- en seriële datapinnen zijn die worden gebruikt voor I2C-communicatie.

Na het maken van het I2C-object wordt er een Adafruit_SGP30-object aangemaakt met behulp van de adafruit_sgp30-module en geeft het het I2C-object als argument mee. Dit staat om te communiceren met de Adafruit SGP30-sensor via het I2C-object en de bijbehorende pinnen.

In deze code werd SGP30 gebruikt. Op de nieuwe PCB wordt de SGP40 variant gebruikt.

In deze functie wordt 15 seconden lang een meting gedaan. Er wordt eerst een tijd ingesteld omdat de gassensor een enig tijd (ongeveer 10 seconden) nodig heeft om een meting waar te maken. Pas vanaf deze tijd kan er bruikbaar data uitgelezen worden.

Sgp30.iaq_measure leest bijgevolg de CO2 en TVOC uit binnen de ingestelde tijd. Hierna wordt de data met het juiste formaat gestuurd via send_message.

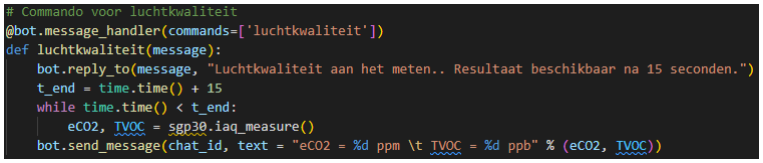
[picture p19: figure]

4.1.1.9 Microfoon (nieuwe hardware)
Er werd ook aan de microfoon gewerkt om deze uit te lezen. Met behulp van een ADC-component is er geprobeerd om via SPI-data op te halen. Er kon enigszins data verzameld worden maar deze leken niets te maken met de werkelijkheid.

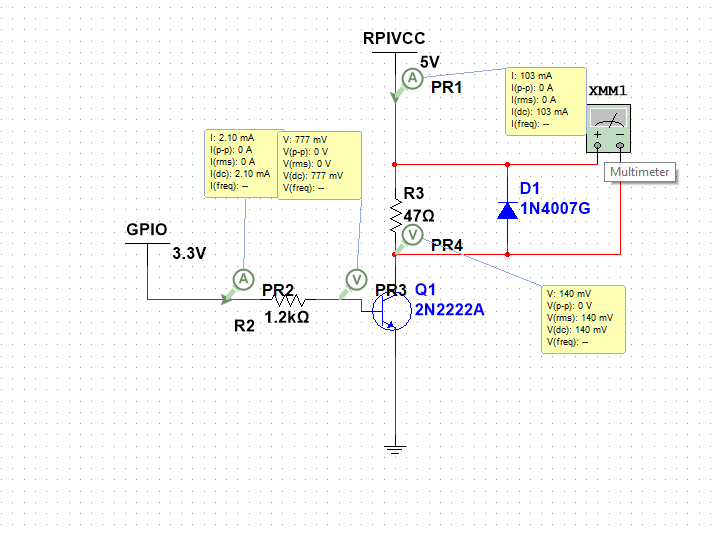
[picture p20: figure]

### 4.2 Circuit

4.2.1 Relais aansturen
Het relais dat gebruikt wordt heeft een spoelspanning van 5V. De spoel weerstand is 47 ohm. In het multisim schakeling stelt dus de 47 ohm weerstand de spoel voor. De spoel stroom is 100mA en dit is de stroom die door de spoel zal vloeien als er geen andere componenten in de kring zitten. De flyback diode wordt gebruikt om het circuit te beschermen tegen spanningspieken bij het afschakelen van de spoel. De 1.2 kOhm weerstand aan de GPIO zorgt ervoor dat er 0.7 V op de basis van de BJT valt. Deze basis trekt dat 2.10mA door een spanning van 2.6V over een weerstand van 1.2kOhm.

4.2.2 SGP 40 applicatie circuit
De basis circuit van een SGP40 bevat een RC-circuit aan de VDD-ingang. Dit zal de ingang spanning vloeiender maken. De twee Rp weerstanden zijn pull up resistors om de SDA en SCL-pins hoog te houden voor een logic 1. De SDA-uitgang kan het spanningsniveau aan zijn uitgang dan laag trekken naar een logic 0. Dit is ook zo bij de SCL. De SGP-ingang zal een logic 1 binnenkrijgen wanneer de microcontroller niks doet. De microcontroller kan dit dan laag trekken en dan zal het signaal aan de SCL een logic 0 zijn.

4.2.3 Analoog microfoon circuit

De term2 van de microfoon is verbonden met de case. Deze wordt dat verbonden met de ground. De analoge microfoon bezit een ECM-unit. Dit maakt dit een ECM-microfoon. Dit ECM-unit is een materiaal dat elektrische lading genereert op geluid. De FET impedance converted versterkt het signaal en verlaagt de impedantie. De Vs regelt de referentie spanning voor de FET en de condensator filtert hoog frequentie signalen weg.

4.2.4 LTC1864 ADC
De condensator aan de ingang zal de ingang spanning stabiel houden. In de opstelling wordt deze ADC gebruikt om de microfoon in te lezen. Dus zal Vref op 5V gezet worden. De IN- ingang zal naar de ground getrokken worden omdat er enkel positief ingelezen moet worden.

4.2.5 PCB
De PCB is ontworpen met als bedoeling

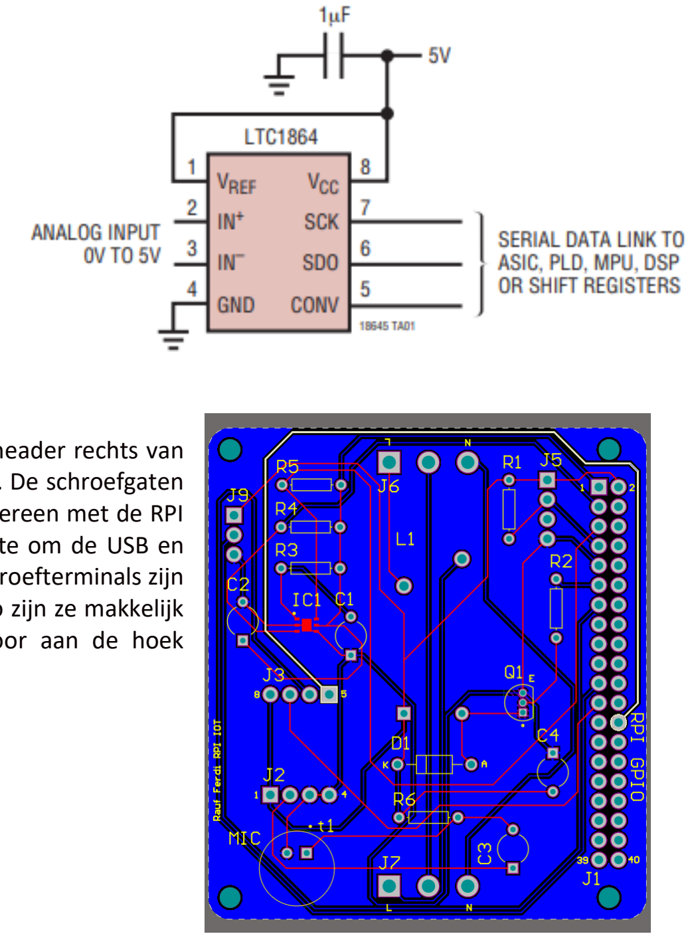
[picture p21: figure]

dat het op de RPI gaat zitten. De 40 pin header rechts van de PCB komt overeen met de RPI-header. De schroefgaten komen ook overeen. De breedte komt overeen met de RPI maar de PCB is iets beperkter in de lengte om de USB en Ethernet poorten niet te hinderen. De schroefterminals zijn geplaatst aan de onder en boven kant. Zo zijn ze makkelijk bereikbaar. De microfoon is ook hiervoor aan de hoek geplaatst.

## 5 Conclusie

Buiten de huidige PCB is er ook gewerkt aan een nieuwe PCB. Deze PCB bevat nieuwe hardware boven op de vorige versie. Wat er zeker besloten kan worden is dat Telegram bot het toe laat om deze hardware aan te sturen. Hierbij kan er als advies gegeven worden dat de nieuwe ontwikkelde PCB geïmplementeerd kan worden op de Raspberry Pi en de nodige hardware aan te sturen.

“Het gebruik van de Telegram bot in combinatie met de bijbehorende hardware was een succes. De sensoren (DHT11, camera, gassensor) functioneerden naar behoren en waren gemakkelijk te integreren met de bot via de API. Het relais werd ook efficiënt aangestuurd en kon worden gebruikt om apparaten aan en uit te zetten. In het algemeen was de Telegram bot een handig hulpmiddel voor het monitoren en aansturen van de hardware.”

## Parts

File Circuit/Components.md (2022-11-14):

# Hardware
TO BE UPDATED

## RPI componenten
| Component | Beschrijving | Aantal |
|---|---|---|
| RPI 3b | Raspberry Pi 3b | 1 |
| 16GB SD | SD kaart 16GB | 1 |
| RPI camera | Raspberry Pi Camera | 1 |
| Micro USB adapter | Micro USB Adapter | 1 |

## Circuit componenten
| Component | Beschrijving | Hoeveelheid |
|---|---|---|
| DHT-11 | Temperatuur-Luchtvochtigheid sensor | 1 |
| G5PZ-1A-E 5VDC | Relais - Spoel 5V | 1 |
| LDR | Lichtgevoelige weerstand | 1 |
| | ADC (Analoog-Digitaal Converter) | 1 |
| DYP-ME003 | Beweging sensor | 1 |
| 2n2222a | NPN BJT Transistor | 1 |
| 1x3 | Schroef terminal | 2 |
| 2x20 | RPI Header | 1 |
| 1n4007g | Flyback Diode | 1 |
| 10kohm | Weerstand | 2 |
| 910ohm | Weerstand | 1 |
| | Accelerometer Module | 1 |

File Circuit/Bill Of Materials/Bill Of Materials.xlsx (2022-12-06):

Component | Hoeveelheid | Voorraad | Comment
DHT11 | 1 | Hebben we | (Lossolderen vorig bordje of extra voorraad) eventueel Rauf
PIR | 1 | Hebben we | (Lossolderen vorig bordje of extra voorraad)
Mic | 1 | Hebben we | Rauf
4x1 female headers | 3 | Hebben we? | Deze hebben we nodig als we niet direct de dht11 en adc op het bordje willen solderen
3x1 female headers | 1 | Hebben we? | Deze hebben we nodig als we niet direct de PIR op het bordje willen solderen
20x2 RPI header | 1 | https://www.reichelt.com/be/nl/raspberry-pi-stacking-header-40-polig-rm-2-54-rpi-header-40-p223626.html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
LTC1864(ADC/SPI) | 1 | Hebben we
SGP40 | 1 | https://www.mouser.be/ProductDetail/Sensirion/SGP40-D-R4?qs=yqaQSyyJnNgaRqiZfsbS1Q%3D%3D
3x1 screw terminal | 2 | Hebben we | (Lossolderen vorig bordje of extra voorraad)
5V relais | 1 | Hebben we | (Lossolderen vorig bordje of extra voorraad)
2n2222a BJT | 1 | Hebben we
n14007g | 1 | Hebben we
Resistor 10kohm | 3 | https://www.mouser.be/ProductDetail/Vishay-Beyschlag/MBA02040C1002FC100?qs=nlQjf3QnJCoHnMMMaOw%2FFA%3D%3D | Trough hole
Resistor 1.2kohm | 1 | https://www.mouser.be/ProductDetail/Xicon/271-1.2K-AP-RC?qs=iPumNTI%2F3jUWQQh5z%252BEsaQ%3D%3D | Trough hole
Resistor 2.2kohm | 1 | https://www.mouser.be/ProductDetail/Xicon/270-2.2K-REEL-RC?qs=MAEpswqNOTF%252BDy94dO%252Bf0Q%3D%3D | Trough hole
Resistor 4.7kohm | 1 | https://www.mouser.be/ProductDetail/Vishay-Dale/CMF504K7000FKR6?qs=D8ivcil3Vuyw9OP34SfELQ%3D%3D | Trough hole
Ceramic Capacitor 1µF | 4 | https://www.mouser.be/ProductDetail/Vishay-BC-Components/K105K20X7RF53H5G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 | Trough hole (Niet elco)
 | 25

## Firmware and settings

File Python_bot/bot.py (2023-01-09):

# Libs
import telebot
import os
from picamera import PiCamera
import Adafruit_DHT
import RPi.GPIO as GPIO
import time
import asyncio
from gpiozero import MotionSensor
import board
import busio
import adafruit_sgp30

API_KEY = ''
chat_id = ''

bot = telebot.TeleBot(API_KEY)

# Resolutie camera instellen
camera = PiCamera()
camera.resolution = (640,480)

# DHT declareren
dht_sensor = Adafruit_DHT.DHT11
# GPIO voor dht sensor
gpio_sensor = 18

# Relais declareren
GPIO.setmode(GPIO.BCM)
gpio_relais = 21
GPIO.setup(gpio_relais, GPIO.OUT)

# Bewegingssensor declareren
pir = MotionSensor(24)

"""i2c = busio.I2C(board.SCL, board.SDA, frequency=100000)

# Create library object on our I2C port
sgp30 = adafruit_sgp30.Adafruit_SGP30(i2c)"""

# Commando voor simpele reply
@bot.message_handler(commands=['hallo'])
def hallo(message):
    bot.reply_to(message, "Hi from TELEBOT!!!!!!")

# Commando voor foto
@bot.message_handler(commands=['foto'])
def foto(message):
    bot.reply_to(message, "Foto is onderweg...")
    # Capture
    camera.capture('/home/pem/Desktop/pem_python/image.jpg')
    # Foto sturen via telegram
    bot.send_photo(chat_id, photo=open('/home/pem/Desktop/pem_python/image.jpg', 'rb'))
    
# Commando voor DHT
@bot.message_handler(commands=['temperatuur'])
def temperatuur(message):
    bot.reply_to(message, "Temperatuur wordt gemeten...")
    # Meting
    humidity, temperature = Adafruit_DHT.read_retry(dht_sensor, gpio_sensor)
    # Meting sturen via telegram
    bot.reply_to(message, 'Temp={0:0.1f}°C  Humidity={1:0.1f}%'.format(temperature, humidity))

# Commando voor aanzetten relais
@bot.message_handler(commands=['relais_aan'])
def relais_aan(message):
    bot.reply_to(message, "Relais wordt aangezet")
    GPIO.output(gpio_relais, GPIO.HIGH)

# Commando voor uitzetten relais
@bot.message_handler(commands=['relais_uit'])
def relais_uit(message):
    bot.reply_to(message, "Relais wordt uitgezet")
    GPIO.output(gpio_relais, GPIO.LOW)

# Commando voor aanzetten bewegingssensor
@bot.message_handler(commands=['motion_aan'])
def motion_aan(message):
    bot.reply_to(message, "Bewegingssensor wordt aangezet")
    motion_det()

"""# Commando voor luchtkwaliteit
@bot.message_handler(commands=['luchtkwaliteit'])
def luchtkwaliteit(message):
    bot.reply_to(message, "Luchtkwaliteit aan het meten.. Resultaat beschikbaar na 15 seconden.")
    t_end = time.time() + 15
    while time.time() < t_end:
        eCO2, TVOC = sgp30.iaq_measure()
    bot.send_message(chat_id, text = "eCO2 = %d ppm \t TVOC = %d ppb" % (eCO2, TVOC))"""

# Aansturen bewegingssensor
def motion_det():
    while True:
        if pir.motion_detected:
            bot.send_message(chat_id, text = "Beweging gedetecteerd! -> " + " " + (time.strftime("%H:%M:%S")))
            time.sleep(3)
        else:
            time.sleep(3)


bot.polling()

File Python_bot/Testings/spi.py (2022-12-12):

import time
import spidev

spi_ch = 0

# Enable SPI
spi = spidev.SpiDev(0, spi_ch)
spi.open(0,0)
spi.max_speed_hz = 20000000

def read_adc(adc_ch, vref = 5):

    # Make sure ADC channel is 0 or 1
    if adc_ch != 0:
        adc_ch = 1

    # Construct SPI message
    #  First bit (Start): Logic high (1)
    #  Second bit (SGL/DIFF): 1 to select single mode
    #  Third bit (ODD/SIGN): Select channel (0 or 1)
    #  Fourth bit (MSFB): 0 for LSB first
    #  Next 12 bits: 0 (don't care)
    msg = 0b11
    msg = ((msg << 1) + adc_ch) << 5
    msg = [msg, 0b00000000]
    reply = spi.xfer2(msg)

    # Construct single integer out of the reply (2 bytes)
    adc = 0
    for n in reply:
        adc = (adc << 8) + n

    # Last bit (0) is not part of ADC value, shift to remove it
    adc = adc >> 1

    # Calculate voltage form ADC value
    voltage = (vref * adc) / 1024

    return voltage

# Report the channel 0 and channel 1 voltages to the terminal
try:
    while True:
        adc_0 = read_adc(0)
        adc_1 = read_adc(1)
        print("Ch 0:", round(adc_0, 2), "V", "Ch 1:", round(adc_1, 2), "V")
        time.sleep(0.5)

finally:
    spi.close()

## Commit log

2022-10-24 added light sensor md
2022-11-07 ignore plus bom
    [BOM.xlsx]
2022-11-11 RPi spoel circuit
    [BOM.xlsx]
2022-11-11 drectory update
    [BOM.xlsx]
2022-11-14 pull down bij base van bjt
    [BOM.xlsx]
2022-11-14 pulldown => useless, flyback diode
2022-11-27 schematic af
    [Circuit.SchDoc]
2022-11-28 pcb components placed
    [RPI-SENSORS.PcbDoc]
2022-11-28 updated schematic
    [Circuit.SchDoc, RPI-SENSORS.PcbDoc]
2022-11-28 components placed
    [Circuit.SchDoc, RPI-SENSOR.PcbDoc, Workshop-IOT.PrjPcb]
2022-11-28 gaten op PCb gezet en alles geordend
    [RPI-SENSOR.PcbDoc]
2022-11-28 board shape
    [RPI-SENSOR.PcbDoc]
2022-12-04 spi - mic
2022-12-05 new components
    [Circuit.SchDoc]
2022-12-05 pcb progress
    [Circuit.SchDoc, Workshop-IOT.PrjPcb]
2022-12-05 pcb wired
    [Circuit.SchDoc]
2022-12-05 PCb aangemaakt
    [Circuit.SchDoc, RPI-SENSOR.PcbDoc, RPI-SENSORS.PcbDoc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]
2022-12-05 Final Board Shazpe
    [RPI-SENSORS.PcbDoc]
2022-12-05 PCB compoennts placed
    [Circuit.SchDoc, RPI-SENSORS.PcbDoc]
2022-12-05 polygoon pour
    [RPI-SENSORS.PcbDoc]
2022-12-05 polygon bottom latyetr
    [Circuit.SchDoc, RPI-SENSORS.PcbDoc]
2022-12-06 pcb schematic mic en adc geupdated
    [Circuit.SchDoc, RPI-SENSORS.PcbDoc]
2022-12-06 PCb af plus gerbers exported
    [Circuit.SchDoc, RPI-SENSORS.PcbDoc, Workshop-IOT.PrjPcb]
